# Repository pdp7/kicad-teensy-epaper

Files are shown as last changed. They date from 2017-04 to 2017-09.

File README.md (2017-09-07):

# E-Paper Badge with Teensy LC designed in KiCad
E-Paper badge designed in [KiCad](http://kicad-pcb.org/) to connect [Pervasive Displays 2.15" E-Paper](http://www.digikey.com/product-detail/en/pervasive-displays/E2215CS062/E2215CS062-ND/5975949) to [Teensy LC](http://store.oshpark.com/products/teensy-lc). _([Teensy 3.2](https://oshpark.com/teensy) is also compatible)._  Based [Teensy E-Paper Shield](https://blog.oshpark.com/2016/08/27/teensy-e-paper-shield/) by [Jarek Lupinski](https://hackaday.io/Jarek) in EAGLE.

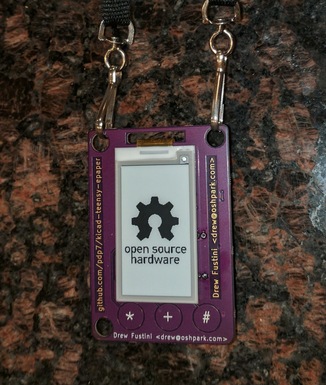
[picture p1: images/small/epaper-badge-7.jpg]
Photo of E-Paper Display (https://oshpark.com/shared_projects/VzRNemk1)

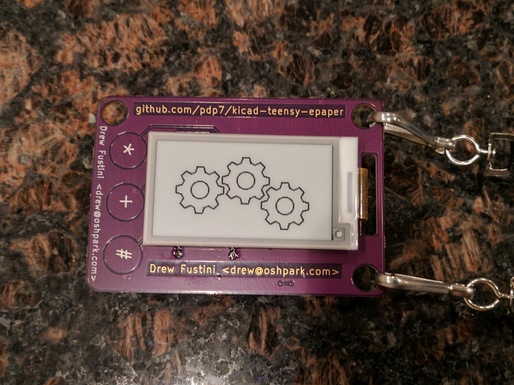
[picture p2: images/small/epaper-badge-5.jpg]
Additional Photo of E-Paper Display (https://oshpark.com/shared_projects/VzRNemk1)


## OSH Park shared project
* [KiCad Teensy E-Paper Badge](https://oshpark.com/shared_projects/VzRNemk1)

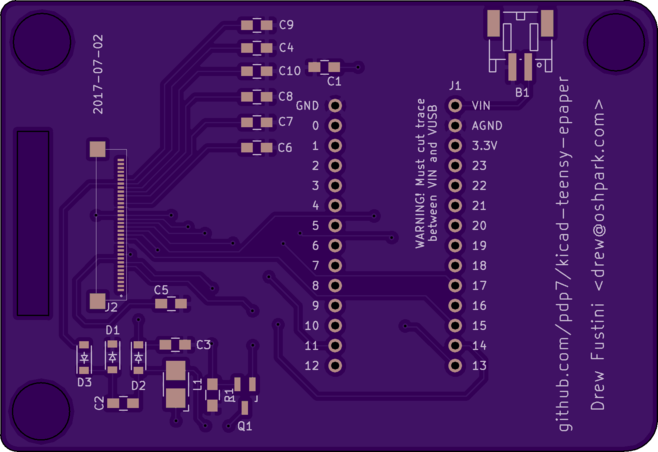
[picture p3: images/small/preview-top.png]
Preview of PCB top side (https://oshpark.com/shared_projects/VzRNemk1)


## KiCad PCB design files
* repo: [kicad-teensy-epaper](https://github.com/pdp7/kicad-teensy-epaper/)
* commit: [add JST connector for lipo battery [abcafec]](https://github.com/pdp7/kicad-teensy-epaper/commit/abcafeccad423acb4cc5d59347c79b58a7b5082b)
* requires KiCad library [wickerlib](https://github.com/wickerbox/wickerlib) by [Jenner Hanni](http://jennerhanni.net/) of [Wickerbox Electronics](http://wickerbox.net/) for the 34-position FPC connector that the e-paper display plugs into:
  * [CONN-HEADER-FH34SRJ-34S-0.5SH.kicad_mod](https://github.com/wickerbox/wickerlib/blob/master/libraries/Wickerlib.pretty/CONN-HEADER-FH34SRJ-34S-0.5SH.kicad_mod)

## Bill of Materials (BoM)
* [OSH Stencils](https://www.oshstencils.com/#projects/83952319ea2abc27d46ef9cab843063dbfd85e58): stainless steel stencil
* [Teensy LC](http://store.oshpark.com/products/teensy-lc) sold by OSH Park. Designed and manufactured by [PJRC](https://www.pjrc.com/teensy/teensyLC.html).
  * _[Teensy 3.2](https://oshpark.com/teensy) is also compatible but more expensive_
* [Pervasive Displays 2.15" e-paper with ITC](http://www.pervasivedisplays.com/products/215)
  * Mfg part number: E2215CS062
  * Digi-Key: [E2215CS062-ND](http://www.digikey.com/product-detail/en/pervasive-displays/E2215CS062/E2215CS062-ND/5975949)
  * Datasheet: [2.15" TFT EPD Panel (E2215CS062)](http://www.pervasivedisplays.com/LiteratureRetrieve.aspx?ID=232067)
  * App note: [2.15" Aurora_Mb Application Note](http://www.pervasivedisplays.com/LiteratureRetrieve.aspx?ID=232068)
* [Hirose FH34SRJ-34S-0.5SH FPC connector](https://www.digikey.com/short/3hv1q0)
  * Mfg part number: FH34SRJ-34S-0.5SH(99)
  * Digi-Key: [H124726CT-ND](https://www.digikey.com/short/3hv1q0)
  * Datasheet: [FH34(S) Series Datasheet](https://www.hirose.com/product/en/download_file/key_name/FH34SRJ/category/Catalog/doc_file_id/31646/?item_id=27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)
* [JST connector for LiPo battery](https://www.digikey.com/short/312bmm)
  * Mfg part number: S2B-PH-SM4-TB(LF)(SN)
  * Digikey: [455-1749-1-ND](https://www.digikey.com/short/312bmm) _(CONN HEADER PH SIDE 2POS 2MM SMD)_
  * Datasheet: [JST PH connector](http://www.jst-mfg.com/product/pdf/eng/ePH.pdf)  
* Teensy headers
  * Digikey: [S7012-ND](https://www.digikey.com/short/3db830) _(CONN HEADER FEMALE 14POS.1" TIN)_
  * optional as Teensy can be soldered directly to PCB
* Capacitor 1uF 0805 _(quantity 9)_
  * Digi-Key: [1276-1066-1-ND](https://www.digikey.com/short/3db8tm) _(CAP CER 1UF 25V X7R 0805)_
  * Reference: C1 C3 C4 C5 C6 C7 C8 C9 C10
  * _Note: it is cheaper to purhcase qty 10_
* Capacitor 2.2uF 0805
  * Digi-Key: [1276-2953-1-ND](https://www.digikey.com/short/3db8tp) _(CAP CER 2.2UF 25V X7R 0805)_
  * Reference: C2
* Inductor 47uH
  * Digi-Key: [732-7252-1-ND](https://www.digikey.com/short/3db8tq) _(FIXED IND 47UH 800MA 521 MOHM)_
  * Reference: L1
* Mosfet N-Ch SOT23
  * Digi-Key: [785-1012-1-ND](https://www.digikey.com/short/3db8t8) _(MOSFET N-CH 30V 3.8A SOT23)_
  * Reference: Q1
* Resistor 2.2 Ohm 0805
  * Digi-Key: [311-2.20CRCT-ND](https://www.digikey.com/short/3db8tz) _(RES SMD 2.2 OHM 1% 1/8W 0805)_
  * Reference: R1
* Schotty diodes SOD123 _(quantity 3)_
  * Digi-Key: [MBR0530CT-ND](https://www.digikey.com/short/3db883) _(DIODE SCHOTTKY 30V 500MA SOD123)_
  * Reference: D1 D2 D3

### [Digi-Key shopping cart](http://www.digikey.com/short/312b57)
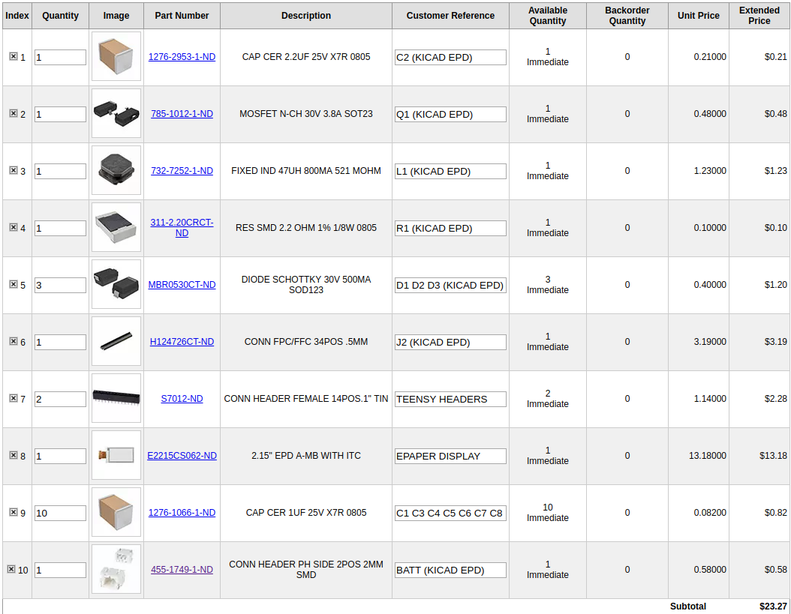
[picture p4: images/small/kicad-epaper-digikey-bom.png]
Digi-Key shopping cart


### Battery Power
* **WARNING: The trace between VIN and VUSB must be cut!**
  * [Demostration of cutting the trace](https://learn.adafruit.com/assets/28069) on Adafruit Learning System.
* **[Lithium Ion Polymer Battery - 3.7v 500mAh](https://www.adafruit.com/product/1578)** from Adafruit
  * capacity chosen for a good trade off between weight and power
  * TODO: measure how long board will run with different capacities.

## Source Code
* uses [EPD215](https://github.com/jarek319/EPD215) Arduino Library by Jarek Lupinski for his E-paper Teensy Shield
* requires pinout modification:
  * example: [bringahackmfba17-dorkbotpdx.ino](https://github.com/pdp7/kicad-teensy-epaper/blob/master/firmware/bringahackmfba17-dorkbotpdx/bringahackmfba17-dorkbotpdx.ino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)
  * `EPD215 epaper( 17, 16, 14, 15, 13, 11 );`
 * rotation hack in [`EPD215.cpp`](https://github.com/pdp7/EPD215/commit/f4e22660877759e53a3a83ed35c6e7a54616d285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)
   * text and graphics wil be upside down without this
   * [quick hack to set rotation](https://github.com/pdp7/EPD215/commit/f4e22660877759e53a3a83ed35c6e7a54616d285) based on [Adafruit documentation](https://learn.adafruit.com/adafruit-gfx-graphics-library/rotating-the-display): 
   * Landscape mode:
     * `_rotation = 1`
   * Portrait mode:
     * `_rotation = 2`
   * I don't use this for the examples program that just display bitmaps as I just flip the image before generating the byte array from the bitmap file

**TODO:** library should be modified to accept rotation parameter
  
## Photos
* [Google Photos gallery](https://goo.gl/photos/csZV9jxah2BSP6vG9)
* [images directory in github repo](https://github.com/pdp7/kicad-teensy-epaper/tree/master/images)

## Video
* [YouTube: *E-Paper Badge with Teensy LC designed in KiCad*](https://www.youtube.com/watch?v=AxnLgPFTEOA)

## Related: Jarek's ePaper Teensy shield
  * OSH Park shared project: [Teensy e-Paper shield](https://oshpark.com/shared_projects/3KynIVn6)
  * My repo of Jarek's design files: [TeensyEpaperShield](https://github.com/pdp7/TeensyEpaperShield)

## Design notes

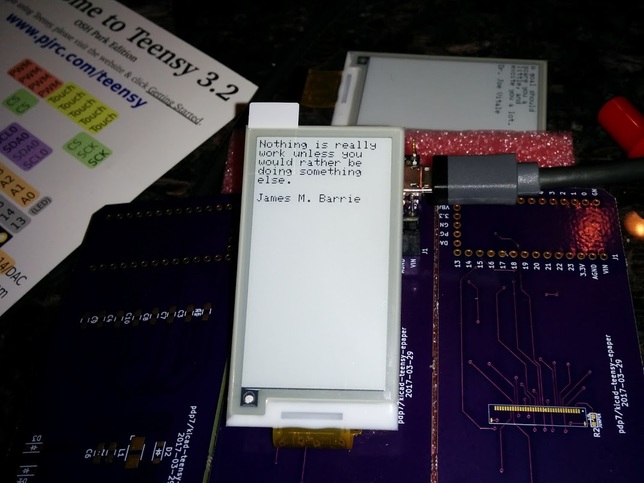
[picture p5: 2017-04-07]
images/small/epaper-breakout-board-quotes.jpg

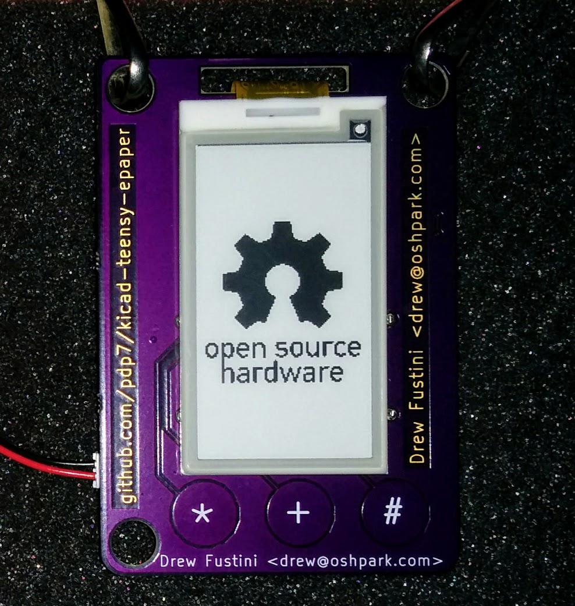
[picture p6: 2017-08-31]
images/front-2.jpg

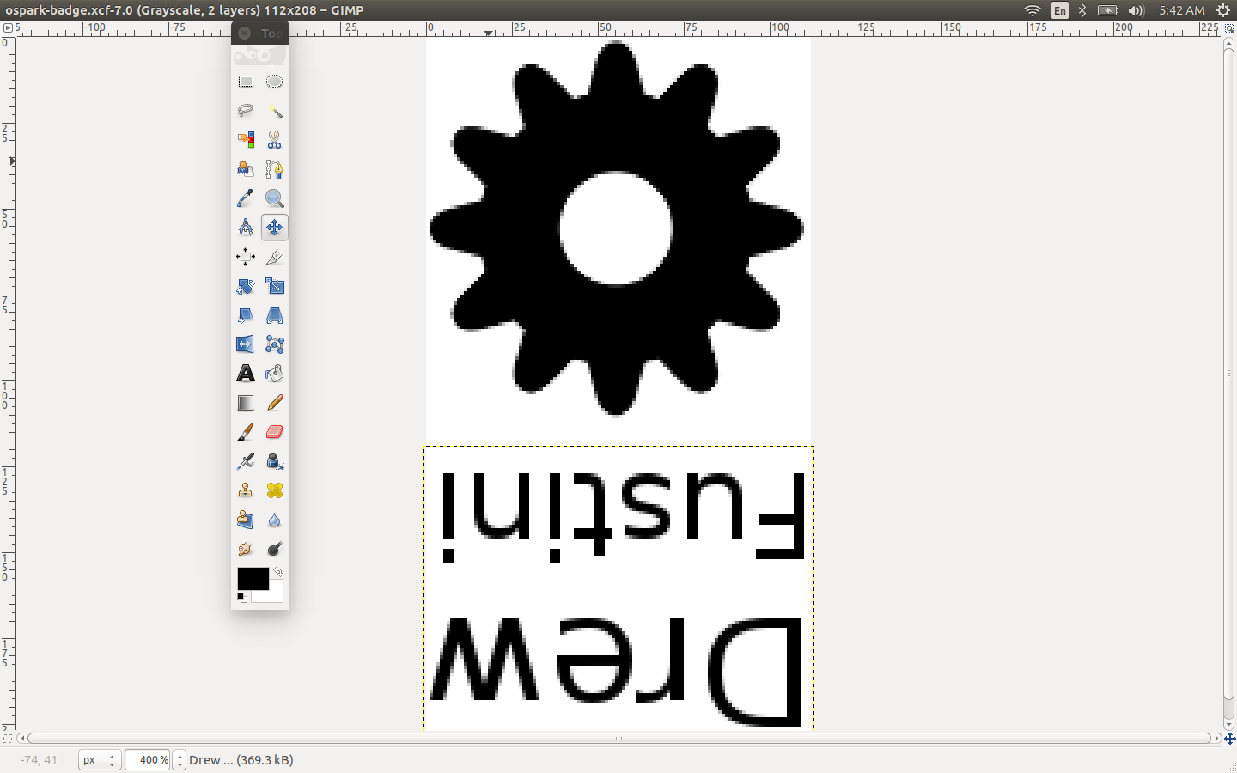
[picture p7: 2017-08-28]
doc/gimp-name.png

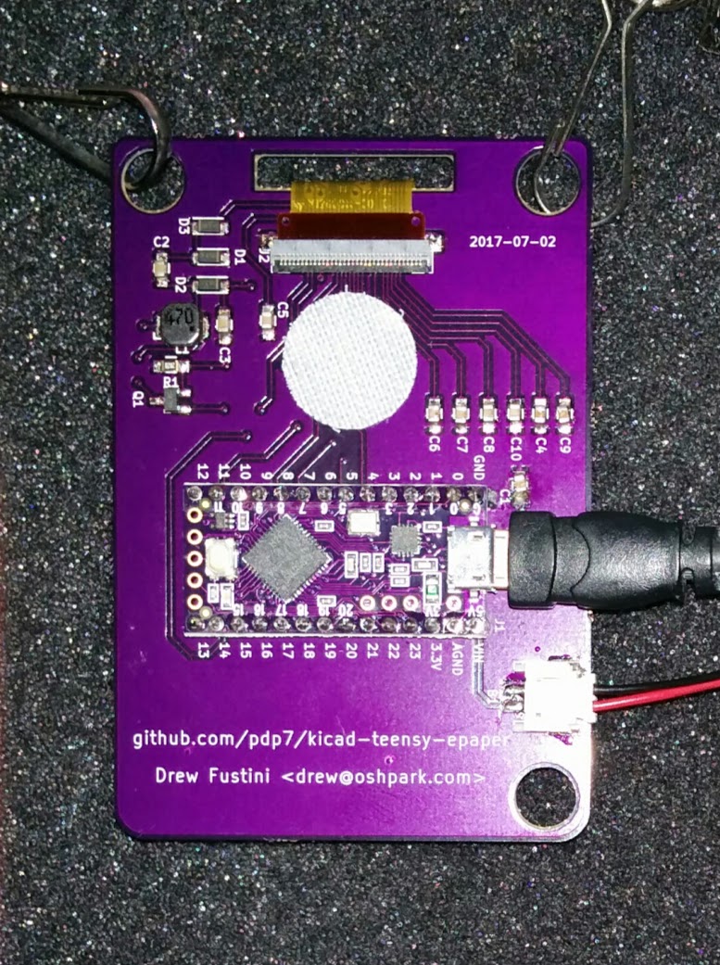
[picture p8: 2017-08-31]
images/back-2.jpg

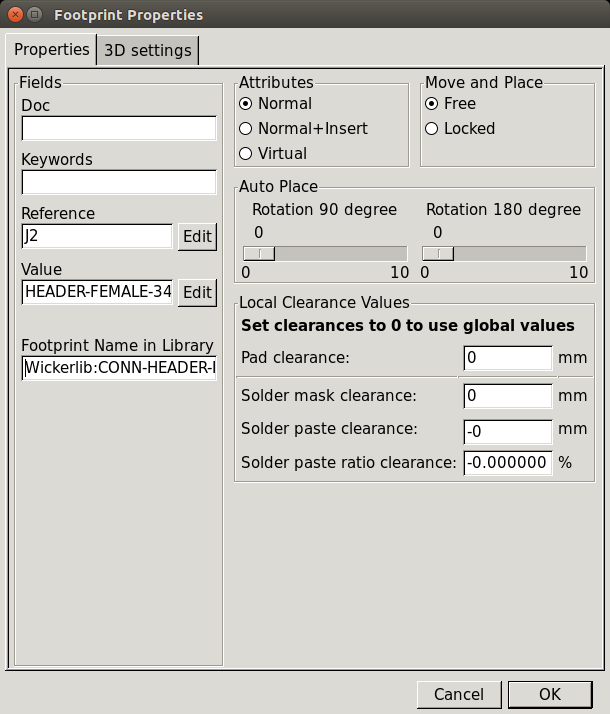
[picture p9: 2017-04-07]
images/fpc-34pos-footprint-props.png

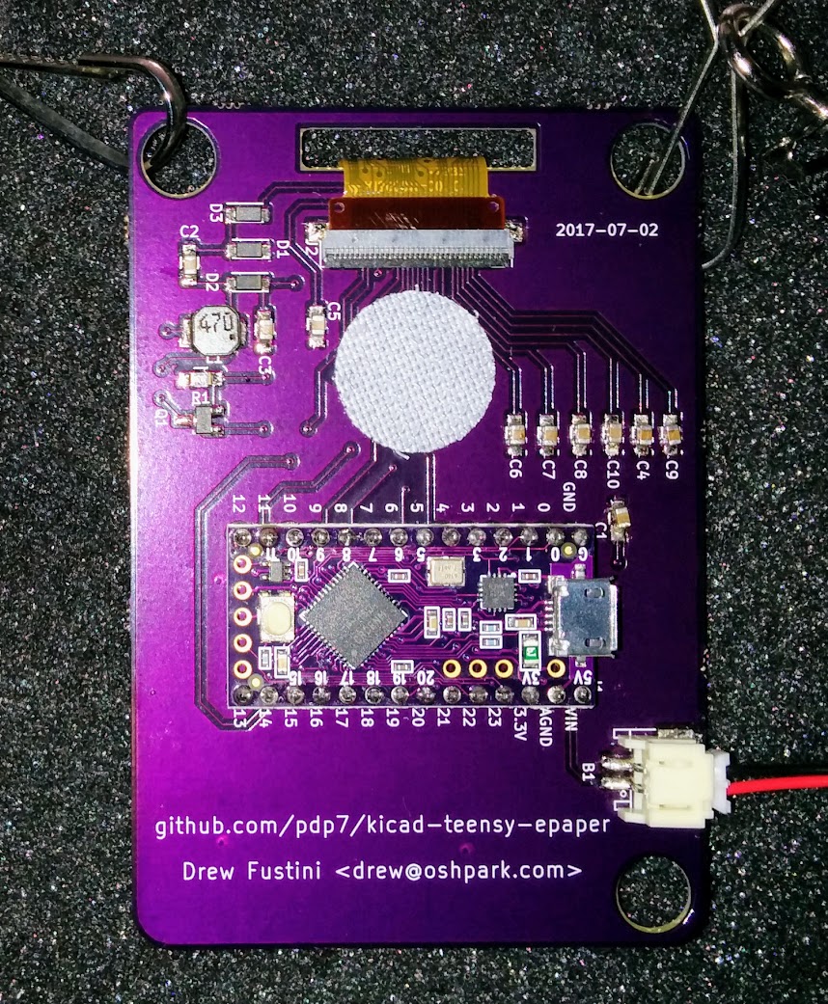
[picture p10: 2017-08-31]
images/back-1.jpg

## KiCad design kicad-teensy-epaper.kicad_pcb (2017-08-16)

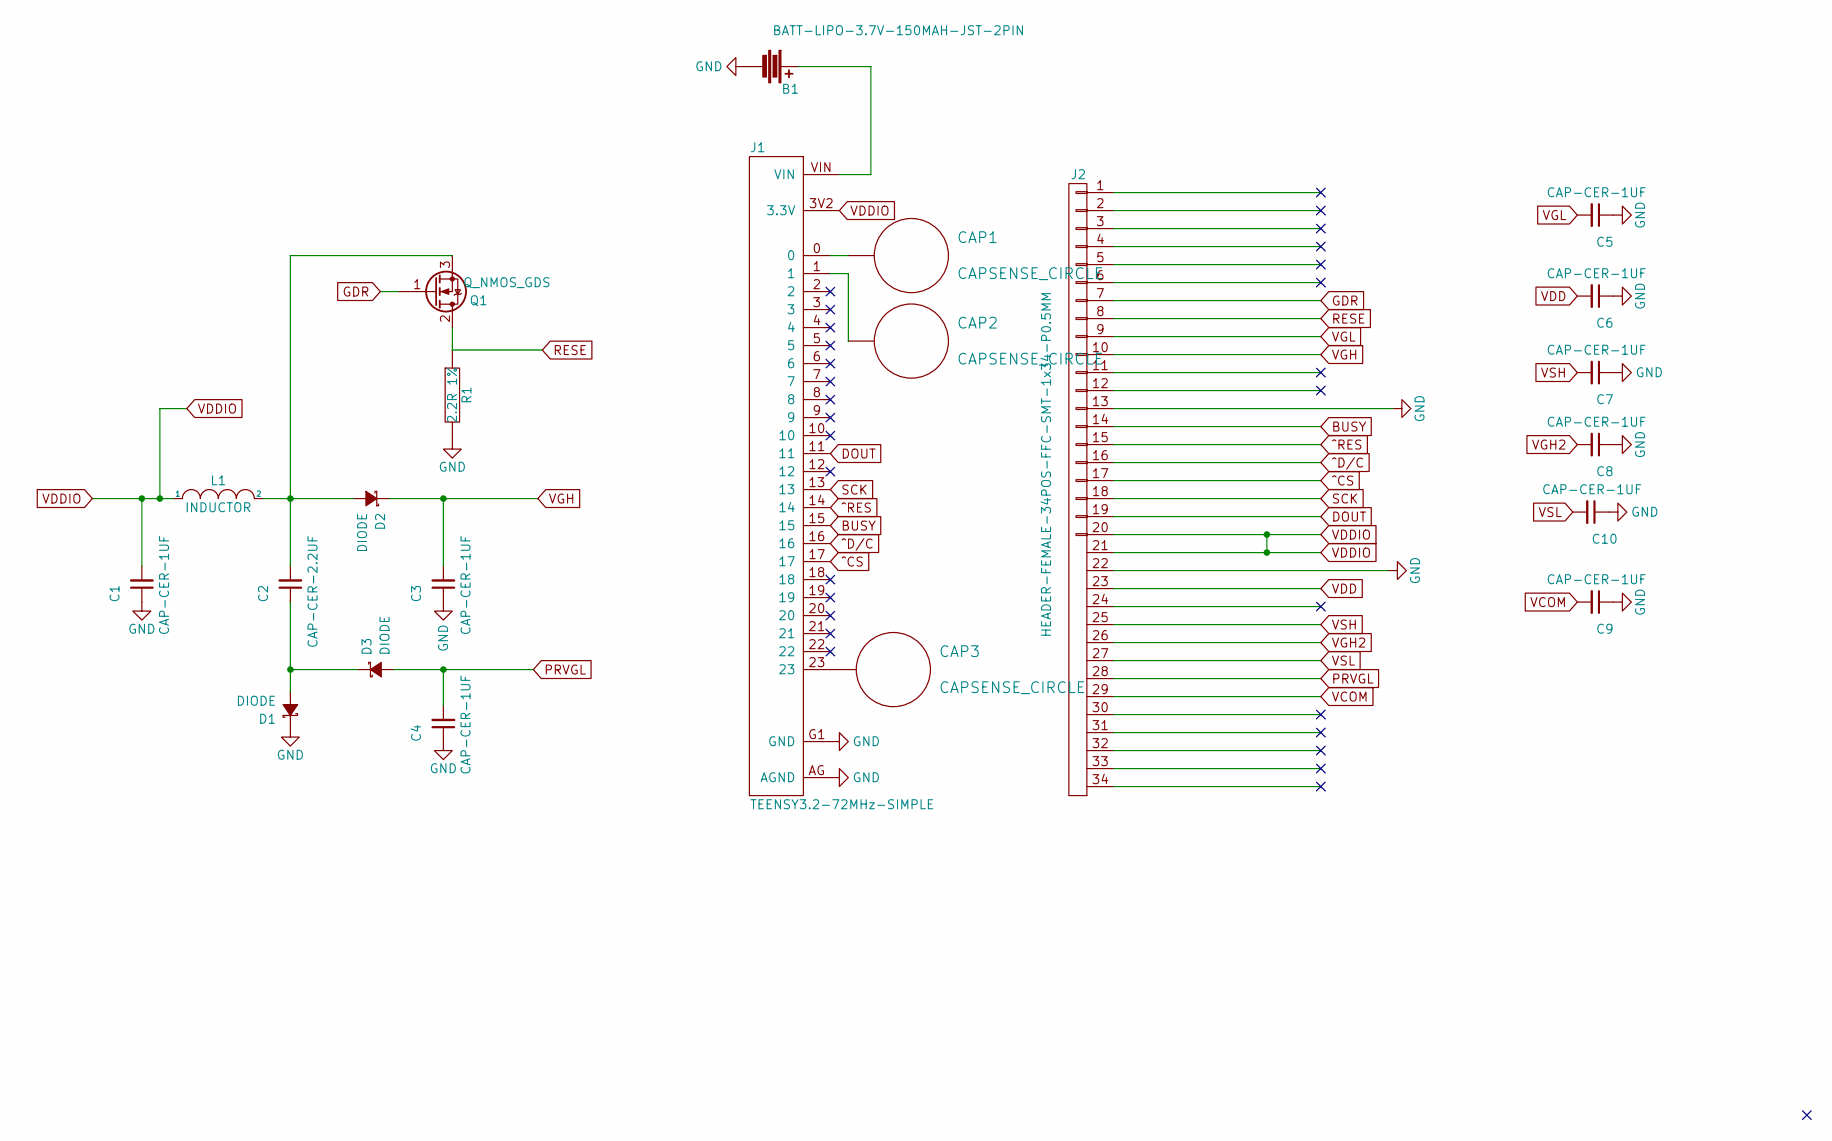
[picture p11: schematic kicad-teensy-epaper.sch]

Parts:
B1: BATT-LIPO-3.7V-150MAH-JST-2PIN; JST_PH_B2B-PH-SM4-TB_02x2.00mm_Straight
C1, C3, C4, C5, C6, C7, C8, C9, C10: CAP-CER-1UF; C_0805_HandSoldering
C2: CAP-CER-2.2UF; C_0805_HandSoldering
CAP1, CAP2, CAP3: CAPSENSE_CIRCLE; CAPSENSE-CIRCLE-D10MM
D1, D2, D3: DIODE; SOD-123
J1: TEENSY3.2-72MHz-SIMPLE; TEENSY-3.2-SILK-SIMPLE
J2: HEADER-FEMALE-34POS-FFC-SMT-1x34-P0.5MM; CONN-HEADER-FH34SRJ-34S-0.5SH
L1: INDUCTOR; Inductor_1212
Q1: Q_NMOS_GDS; SOT-23_Handsoldering
R1: 2.2R 1%; R_0805_HandSoldering

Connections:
BUSY: J1.15, J2.14
DOUT: J1.11, J2.19
GDR: J2.7, Q1.1 (G)
GND: B1.2, C1.1, C3.1, C4.1, C5.1, C6.1, C7.1, C8.1, C9.1, C10.1, D1.1 (K), J1.AG (AGND), J1.G1 (GND), J2.13, J2.22, R1.2
unnamed: B1.1, J1.VIN
unnamed: C2.1, D1.2 (A), D3.1 (K)
unnamed: C2.2, D2.2 (A), L1.2, Q1.3 (S)
unnamed: CAP1.1, J1.0
unnamed: CAP2.1, J1.1
unnamed 9: CAP3.1, J1.23; also elsewhere on the board
PRVGL: C4.2, D3.2 (A), J2.28
RESE: J2.8, Q1.2 (D), R1.1
SCK: J1.13, J2.18
VCOM: C9.2, J2.29
VDD: C6.2, J2.23
VDDIO: C1.2, J1.3V2 (3.3V), J2.20, J2.21, L1.1
VGH: C3.2, D2.1 (K), J2.10
VGH2: C8.2, J2.26
VGL: C5.2, J2.9
VSH: C7.2, J2.25
VSL: C10.2, J2.27
^CS: J1.17, J2.17
^D/C: J1.16, J2.16
^RES: J1.14, J2.15

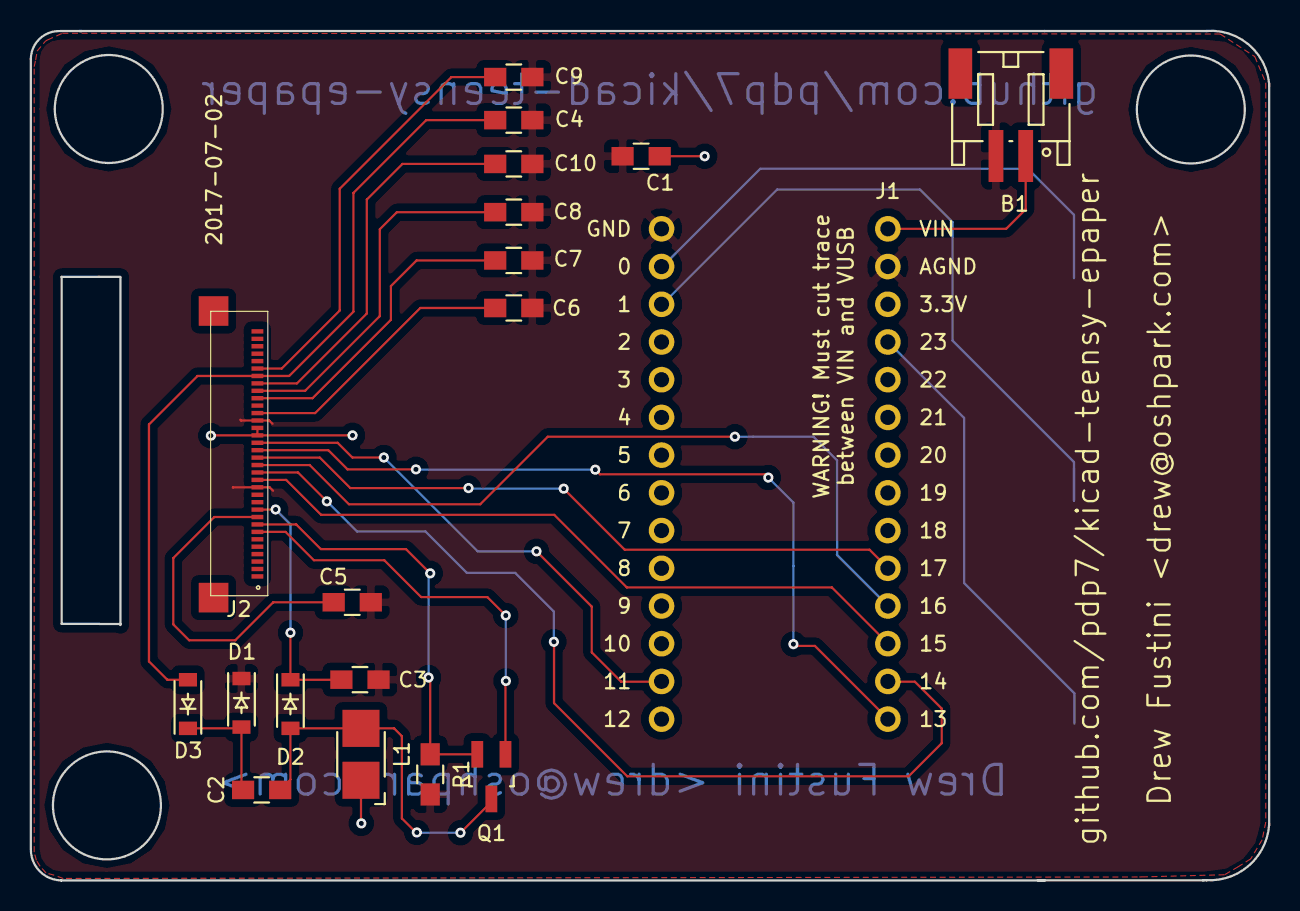
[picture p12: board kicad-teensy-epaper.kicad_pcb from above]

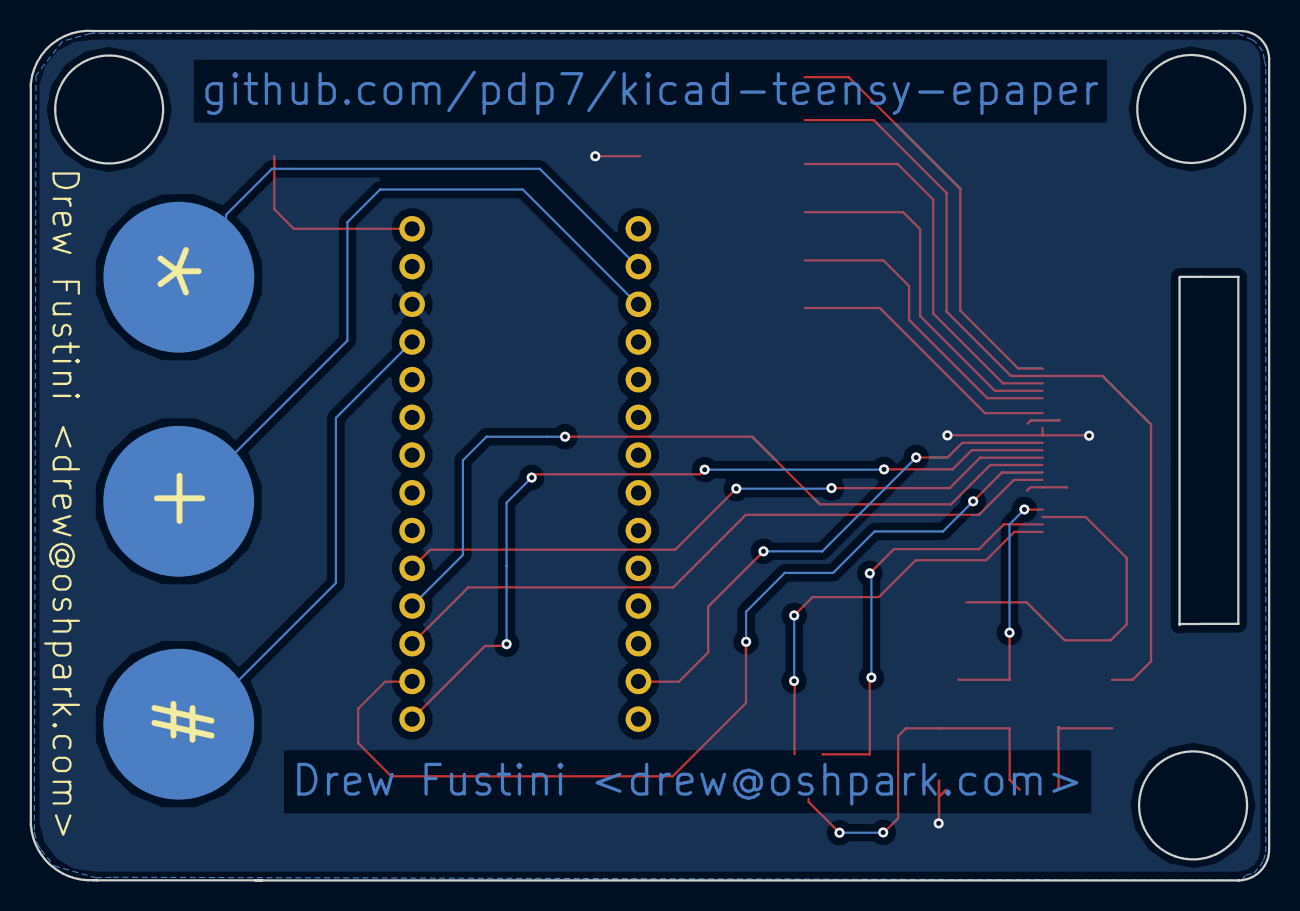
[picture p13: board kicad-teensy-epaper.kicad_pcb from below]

Board: 2 copper layers, 83.4 x 57.2 mm, 22 parts (3 on the bottom side), 24 nets.

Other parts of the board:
A: CAPSENSE_CIRCLE; CAPSENSE-CIRCLE-D10MM

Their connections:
unnamed 9: A.1; also elsewhere on the board

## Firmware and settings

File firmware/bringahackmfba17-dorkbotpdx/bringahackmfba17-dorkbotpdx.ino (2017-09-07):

#include <Adafruit_GFX.h> // include the base Adafruit Graphics library
#include <EPD215.h>       // include the epaper display driver library

// initialize epaper with pin numbers for cs, dc, rs, bs, d0, d1 for software SPI
//EPD215 epaper( 17, 16, 14, 15, 13, 11 );
EPD215 epaper( 17, 16, 14, 15, 13, 11 );


// use the tool at http://javl.github.io/image2cpp/ to generate the block of data below
// settings are: Canvas size/s: 112 x 208 , Draw Mode: Horizontal
// use other settings to make white = 0 and black = 1
const uint8_t bitmap[ 2912 ] = { // overwrite the block of data between the lines with your image data
0x00, 0x00, 0x00, 0x00, 0x00, 0x00, 0x00, 0x00, 0x00, 0x00, 0x00, 0x00, 0x00, 0x00, 0x00, 0x00,
0x00, 0x00, 0x00, 0x00, 0x00, 0x00, 0x00, 0x00, 0x00, 0x00, 0x00, 0x00, 0x00, 0x00, 0x00, 0x00,
0x00, 0x00, 0x07, 0xC0, 0x00, 0x00, 0x00, 0x00, 0x00, 0x00, 0x00, 0x00, 0x00, 0x00, 0x00, 0x00,
0x0F, 0xE0, 0x00, 0x00, 0x00, 0x00, 0x00, 0x00, 0x00, 0x00, 0x00, 0x00, 0x00, 0x00, 0x1F, 0xE0,
0x00, 0x00, 0x00, 0x00, 0x00, 0x00, 0x00, 0x00, 0x00, 0x00, 0x00, 0x00, 0x1F, 0xF0, 0x00, 0x00,
0x00, 0x00, 0x00, 0x00, 0x00, 0x00, 0x00, 0x00, 0x00, 0x00, 0x3F, 0xF0, 0x00, 0x00, 0x00, 0x00,
0x00, 0x00, 0x00, 0x00, 0x00, 0x00, 0x00, 0x00, 0x3F, 0xF8, 0x00, 0x00, 0x00, 0x00, 0x00, 0x00,
0x00, 0x00, 0x00, 0x00, 0x00, 0x00, 0x3F, 0xF8, 0x00, 0x00, 0x00, 0x00, 0x00, 0x00, 0x00, 0x00,
0x00, 0x0F, 0x80, 0x00, 0x7F, 0xF8, 0x00, 0x07, 0xE0, 0x00, 0x00, 0x00, 0x00, 0x00, 0x00, 0x1F,
0xE0, 0x00, 0x7F, 0xF8, 0x00, 0x0F, 0xF0, 0x00, 0x00, 0x00, 0x00, 0x00, 0x00, 0x3F, 0xF0, 0x00,
0x7F, 0xFC, 0x00, 0x1F, 0xF0, 0x00, 0x00, 0x00, 0x00, 0x00, 0x00, 0x3F, 0xF8, 0x00, 0x7F, 0xFC,
0x00, 0x3F, 0xF0, 0x00, 0x00, 0x00, 0x00, 0x00, 0x00, 0x3F, 0xFC, 0x00, 0xFF, 0xFC, 0x00, 0x7F,
0xF0, 0x00, 0x00, 0x00, 0x00, 0x00, 0x00, 0x3F, 0xFE, 0x00, 0xFF, 0xFC, 0x00, 0xFF, 0xF0, 0x00,
0x00, 0x00, 0x00, 0x00, 0x00, 0x3F, 0xFF, 0x00, 0xFF, 0xFE, 0x03, 0xFF, 0xF0, 0x00, 0x00, 0x00,
0x00, 0x00, 0x00, 0x3F, 0xFF, 0x80, 0xFF, 0xFE, 0x07, 0xFF, 0xF0, 0x00, 0x00, 0x00, 0x00, 0x00,
0x00, 0x1F, 0xFF, 0xC3, 0xFF, 0xFF, 0x8F, 0xFF, 0xF0, 0x00, 0x00, 0x00, 0x00, 0x00, 0x00, 0x1F,
0xFF, 0xFF, 0xFF, 0xFF, 0xFF, 0xFF, 0xF0, 0x00, 0x00, 0x00, 0x00, 0x00, 0x00, 0x1F, 0xFF, 0xFF,
0xFF, 0xFF, 0xFF, 0xFF, 0xE0, 0x00, 0x00, 0x00, 0x00, 0x00, 0x00, 0x1F, 0xFF, 0xFF, 0xFF, 0xFF,
0xFF, 0xFF, 0xE0, 0x00, 0x00, 0x00, 0x00, 0x00, 0x00, 0x0F, 0xFF, 0xFF, 0xFF, 0xFF, 0xFF, 0xFF,
0xE0, 0x00, 0x00, 0x00, 0x00, 0x00, 0x00, 0x0F, 0xFF, 0xFF, 0xFF, 0xFF, 0xFF, 0xFF, 0xE0, 0x00,
0x00, 0x00, 0x00, 0x00, 0x00, 0x0F, 0xFF, 0xFF, 0xFF, 0xFF, 0xFF, 0xFF, 0xC0, 0x00, 0x00, 0x00,
0x00, 0x00, 0x00, 0x07, 0xFF, 0xFF, 0xFF, 0xFF, 0xFF, 0xFF, 0xC0, 0x00, 0x00, 0x00, 0x00, 0x00,
0x00, 0x07, 0xFF, 0xFF, 0xFF, 0xFF, 0xFF, 0xFF, 0xC0, 0x00, 0x00, 0x00, 0x00, 0x00, 0x00, 0x07,
0xFF, 0xFF, 0xFF, 0xFF, 0xFF, 0xFF, 0xC0, 0x00, 0x00, 0x00, 0x00, 0x3F, 0xC0, 0x0F, 0xFF, 0xFF,
0xFF, 0xFF, 0xFF, 0xFF, 0xE0, 0x0F, 0xF8, 0x00, 0x00, 0x7F, 0xFC, 0x1F, 0xFF, 0xFF, 0xFF, 0xFF,
0xFF, 0xFF, 0xF0, 0x7F, 0xFC, 0x00, 0x00, 0xFF, 0xFF, 0xFF, 0xFF, 0xFF, 0xFF, 0xFF, 0xFF, 0xFF,
0xFF, 0xFF, 0xFC, 0x00, 0x00, 0xFF, 0xFF, 0xFF, 0xFF, 0xFF, 0xFF, 0xFF, 0xFF, 0xFF, 0xFF, 0xFF,
0xFC, 0x00, 0x00, 0xFF, 0xFF, 0xFF, 0xFF, 0xFF, 0xFF, 0xFF, 0xFF, 0xFF, 0xFF, 0xFF, 0xFC, 0x00,
0x00, 0xFF, 0xFF, 0xFF, 0xFF, 0xFF, 0xFF, 0xFF, 0xFF, 0xFF, 0xFF, 0xFF, 0xFC, 0x00, 0x00, 0x7F,
0xFF, 0xFF, 0xFF, 0xFF, 0xFF, 0xFF, 0xFF, 0xFF, 0xFF, 0xFF, 0xFC, 0x00, 0x00, 0x7F, 0xFF, 0xFF,
0xFF, 0xFF, 0xFF, 0xFF, 0xFF, 0xFF, 0xFF, 0xFF, 0xF8, 0x00, 0x00, 0x3F, 0xFF, 0xFF, 0xFF, 0xFF,
0xFF, 0xFF, 0xFF, 0xFF, 0xFF, 0xFF, 0xF0, 0x00, 0x00, 0x1F, 0xFF, 0xFF, 0xFF, 0xFF, 0xFF, 0xFF,
0xFF, 0xFF, 0xFF, 0xFF, 0xF0, 0x00, 0x00, 0x0F, 0xFF, 0xFF, 0xFF, 0xFF, 0xFF, 0xFF, 0xFF, 0xFF,
0xFF, 0xFF, 0xE0, 0x00, 0x00, 0x07, 0xFF, 0xFF, 0xFF, 0xFF, 0xFF, 0xFF, 0xFF, 0xFF, 0xFF, 0xFF,
0x80, 0x00, 0x00, 0x03, 0xFF, 0xFF, 0xFF, 0xFF, 0xC0, 0x0F, 0xFF, 0xFF, 0xFF, 0xFF, 0x00, 0x00,
0x00, 0x01, 0xFF, 0xFF, 0xFF, 0xFF, 0x00, 0x01, 0xFF, 0xFF, 0xFF, 0xFE, 0x00, 0x00, 0x00, 0x00,
0xFF, 0xFF, 0xFF, 0xFC, 0x00, 0x00, 0x7F, 0xFF, 0xFF, 0xFC, 0x00, 0x00, 0x00, 0x00, 0x7F, 0xFF,
0xFF, 0xF8, 0x00, 0x00, 0x3F, 0xFF, 0xFF, 0xF8, 0x00, 0x00, 0x00, 0x00, 0x3F, 0xFF, 0xFF, 0xF0,
0x00, 0x00, 0x1F, 0xFF, 0xFF, 0xF0, 0x00, 0x00, 0x00, 0x00, 0x7F, 0xFF, 0xFF, 0xE0, 0x00, 0x00,
0x0F, 0xFF, 0xFF, 0xF8, 0x00, 0x00, 0x00, 0x00, 0x7F, 0xFF, 0xFF, 0xC0, 0x00, 0x00, 0x07, 0xFF,
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
};

const uint8_t oshw[ 2912 ] = {
0x00, 0x00, 0x00, 0x00, 0x00, 0x00, 0x00, 0x00, 0x00, 0x00, 0x00, 0x00, 0x00, 0x00, 0x00, 0x00,
0x00, 0x00, 0x00, 0x00, 0x00, 0x00, 0x00, 0x00, 0x00, 0x00, 0x00, 0x00, 0x00, 0x00, 0x00, 0x00,
0x00, 0x00, 0x00, 0x00, 0x00, 0x00, 0x00, 0x00, 0x00, 0x00, 0x00, 0x00, 0x00, 0x00, 0x00, 0x00,
0x00, 0x00, 0x00, 0x00, 0x00, 0x00, 0x00, 0x00, 0x00, 0x00, 0x00, 0x00, 0x00, 0x00, 0x00, 0x00,
0x00, 0x00, 0x00, 0x00, 0x00, 0x00, 0x00, 0x00, 0x00, 0x00, 0x00, 0x00, 0x00, 0x00, 0x00, 0x00,
0x00, 0x00, 0x00, 0x00, 0x00, 0x00, 0x00, 0x00, 0x00, 0x00, 0x00, 0x00, 0x00, 0x00, 0x00, 0x00,
0x00, 0x00, 0x00, 0x00, 0x00, 0x00, 0x00, 0x00, 0x00, 0x00, 0x00, 0x00, 0x00, 0x00, 0x00, 0x00,
0x00, 0x00, 0x00, 0x00, 0x00, 0x00, 0x00, 0x00, 0x00, 0x00, 0x00, 0x00, 0x00, 0x00, 0x00, 0x00,
0x00, 0x00, 0x00, 0x00, 0x00, 0x00, 0x00, 0x00, 0x00, 0x00, 0x00, 0x00, 0x00, 0x00, 0x00, 0x00,
0x00, 0x00, 0x00, 0x00, 0x00, 0x00, 0x00, 0x00, 0x00, 0x00, 0x00, 0x00, 0x00, 0x00, 0x00, 0x00,
0x00, 0x00, 0x00, 0x00, 0x00, 0x00, 0x00, 0x00, 0x00, 0x00, 0x00, 0x00, 0x00, 0x00, 0x00, 0x00,
0x00, 0x00, 0x00, 0x00, 0x00, 0x00, 0x00, 0x00, 0x00, 0x00, 0x00, 0x00, 0x00, 0x00, 0x00, 0x00,
0x00, 0x00, 0x00, 0x00, 0x00, 0x00, 0x00, 0x00, 0x00, 0x00, 0x00, 0x00, 0x00, 0x00, 0x00, 0x00,
0x00, 0x00, 0x00, 0x00, 0x00, 0x00, 0x00, 0x00, 0x00, 0x00, 0x00, 0x00, 0x00, 0x00, 0x00, 0x00,
0x00, 0x00, 0x00, 0x00, 0x00, 0x00, 0x00, 0x00, 0x00, 0x00, 0x00, 0x00, 0x00, 0x00, 0x00, 0x00,
0x00, 0x00, 0x00, 0x00, 0x00, 0x00, 0x00, 0x00, 0x00, 0x00, 0x00, 0x00, 0x00, 0x00, 0x00, 0x00,
0x00, 0x00, 0x00, 0x00, 0x00, 0x00, 0x00, 0x00, 0x00, 0x00, 0x00, 0x00, 0x00, 0x00, 0x00, 0x00,
0x00, 0x00, 0x00, 0x00, 0x00, 0x00, 0x00, 0x00, 0x00, 0x00, 0x00, 0x00, 0x00, 0x00, 0x00, 0x00,
0x00, 0x00, 0x00, 0x00, 0x00, 0x00, 0x00, 0x00, 0x00, 0x00, 0x00, 0x00, 0x00, 0x00, 0x00, 0x00,
0x00, 0x00, 0x00, 0x00, 0x00, 0x00, 0x00, 0x00, 0x00, 0x00, 0x00, 0x00, 0x00, 0x00, 0x00, 0x00,
0x00, 0x00, 0x00, 0x00, 0x00, 0x00, 0x00, 0x00, 0x00, 0x00, 0x00, 0x00, 0x00, 0x00, 0x00, 0x00,
0x00, 0x00, 0x00, 0x00, 0x00, 0x00, 0x00, 0x00, 0x00, 0x00, 0x00, 0x00, 0x00, 0x00, 0x00, 0x00,
0x00, 0x00, 0x00, 0x00, 0x00, 0x00, 0x00, 0x00, 0x00, 0x00, 0x00, 0x00, 0x00, 0x00, 0x00, 0x00,
0x00, 0x00, 0x00, 0x00, 0x00, 0x00, 0x00, 0x00, 0x00, 0x00, 0x00, 0x00, 0x00, 0x00, 0x00, 0x00,
0x00, 0x00, 0x00, 0x00, 0x00, 0x00, 0x00, 0x00, 0x00, 0x00, 0x00, 0x00, 0x00, 0x00, 0x00, 0x00,
0x00, 0x00, 0x00, 0x00, 0x00, 0x00, 0x00, 0x00, 0x00, 0x00, 0x00, 0x00, 0x00, 0x00, 0x00, 0x00,
0x00, 0x00, 0x00, 0x00, 0x00, 0x00, 0x00, 0x00, 0x00, 0x00, 0x00, 0x00, 0x00, 0x00, 0x00, 0x00,
0x00, 0x00, 0x00, 0x00, 0x00, 0x00, 0x00, 0x00, 0x00, 0x00, 0x00, 0x00, 0x00, 0x00, 0x00, 0x00,
0x00, 0x00, 0x00, 0x00, 0x00, 0x00, 0x00, 0x00, 0x00, 0x00, 0x00, 0x00, 0x00, 0x00, 0x00, 0x00,
0x00, 0x00, 0x00, 0x00, 0x00, 0x00, 0x00, 0x00, 0x00, 0x00, 0x00, 0x00, 0x00, 0x00, 0x00, 0x00,
0x00, 0x00, 0x00, 0x00, 0x00, 0x00, 0x00, 0x00, 0x00, 0x00, 0x00, 0x00, 0x00, 0x00, 0x00, 0x00,
0x00, 0x00, 0x00, 0x00, 0x00, 0x00, 0x00, 0x00, 0x00, 0x00, 0x00, 0x00, 0x00, 0x00, 0x00, 0x00,
0x00, 0x00, 0x00, 0x00, 0x00, 0x00, 0x00, 0x00, 0x00, 0x00, 0x00, 0x00, 0x00, 0x00, 0x00, 0x00,
0x00, 0x00, 0x00, 0x00, 0x00, 0x00, 0x00, 0x00, 0x00, 0x00, 0x00, 0x00, 0x00, 0x00, 0x00, 0x00,
0x00, 0x00, 0x00, 0x00, 0x00, 0x00, 0x00, 0x00, 0x00, 0x00, 0x00, 0x00, 0x00, 0x00, 0x00, 0x00,
0x00, 0x00, 0x00, 0x00, 0x00, 0x00, 0x00, 0x00, 0x00, 0x00, 0x00, 0x00, 0x00, 0x00, 0x00, 0x00,
0x00, 0x00, 0x00, 0x00, 0x00, 0x00, 0x00, 0x00, 0x00, 0x00, 0x00, 0x00, 0x00, 0x00, 0x00, 0x00,
0x00, 0x00, 0x00, 0x00, 0x00, 0x00, 0x00, 0x00, 0x00, 0x00, 0x00, 0x00, 0x00, 0x00, 0x00, 0x00,
0x00, 0x00, 0x00, 0x00, 0x00, 0x00, 0x00, 0x00, 0x00, 0x00, 0x00, 0x00, 0x00, 0x00, 0x00, 0x00,
0x00, 0x00, 0x00, 0x00, 0x00, 0x00, 0x00, 0x00, 0x00, 0x00, 0x00, 0x00, 0x00, 0x00, 0x00, 0x00,
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
};

const uint8_t pdx [ 2912 ] = {
  0x00, 0x00, 0x00, 0x00, 0x48, 0x00, 0x00, 0x00, 0x09, 0x00, 0x00, 0x00, 0x00, 0x00, 0x00, 0x00,
0x00, 0x00, 0x48, 0x00, 0x00, 0x00, 0x09, 0x00, 0x00, 0x00, 0x00, 0x00, 0x00, 0x00, 0x00, 0x00,
0x48, 0x00, 0x00, 0x00, 0x09, 0x00, 0x00, 0x00, 0x00, 0x00, 0x00, 0x00, 0x00, 0x00, 0x48, 0x00,
0x00, 0x00, 0x09, 0x00, 0x00, 0x00, 0x00, 0x00, 0x00, 0x00, 0x00, 0x00, 0x48, 0x00, 0x00, 0x00,
0x09, 0x00, 0x00, 0x00, 0x00, 0x00, 0x00, 0x00, 0x00, 0x00, 0x48, 0x00, 0x00, 0x00, 0x09, 0x00,
0x00, 0x00, 0x00, 0x00, 0x00, 0x00, 0x00, 0x00, 0x48, 0x00, 0x00, 0x00, 0x09, 0x00, 0x00, 0x00,
0x00, 0x00, 0x00, 0x00, 0x00, 0x00, 0x48, 0x00, 0x00, 0x00, 0x09, 0x00, 0x00, 0x00, 0x00, 0x00,
0x00, 0x00, 0x00, 0x00, 0x48, 0x00, 0x00, 0x00, 0x09, 0x00, 0x00, 0x00, 0x00, 0x00, 0x00, 0x00,
0x00, 0x00, 0x48, 0x00, 0x00, 0x00, 0x09, 0x00, 0x00, 0x00, 0x00, 0x00, 0x00, 0x00, 0x00, 0x00,
0x40, 0x00, 0x00, 0x00, 0x09, 0x00, 0x00, 0x00, 0x00, 0x00, 0x00, 0x00, 0x00, 0x00, 0x40, 0x00,
0x00, 0x00, 0x09, 0x00, 0x00, 0x00, 0x00, 0x00, 0x00, 0x00, 0x00, 0x00, 0x40, 0x00, 0x00, 0x00,
0x09, 0x00, 0x00, 0x00, 0x00, 0x00, 0x00, 0x00, 0x00, 0x00, 0x44, 0x00, 0x00, 0x00, 0x09, 0x00,
0x00, 0x00, 0x00, 0x00, 0x00, 0x00, 0x00, 0x00, 0x44, 0x00, 0x00, 0x00, 0x09, 0x00, 0x00, 0x00,
0x00, 0x00, 0x00, 0x00, 0x00, 0x00, 0x44, 0x00, 0x00, 0x00, 0x09, 0x00, 0x00, 0x00, 0x00, 0x00,
0x00, 0x00, 0x00, 0x00, 0x64, 0x00, 0x00, 0x00, 0x09, 0x00, 0x00, 0x00, 0x00, 0x00, 0x00, 0x00,
0x00, 0x00, 0x24, 0x00, 0x00, 0x00, 0x09, 0x00, 0x00, 0x00, 0x00, 0x00, 0x00, 0x00, 0x00, 0x00,
0x24, 0x00, 0x00, 0x00, 0x09, 0x00, 0x00, 0x00, 0x00, 0x00, 0x00, 0x00, 0x00, 0x00, 0x24, 0x00,
0x00, 0x00, 0x09, 0x00, 0x00, 0x00, 0x00, 0x00, 0x00, 0x00, 0x00, 0x00, 0x24, 0x00, 0x00, 0x00,
0x09, 0x00, 0x00, 0x00, 0x00, 0x00, 0x00, 0x00, 0x00, 0x00, 0x24, 0x00, 0x00, 0x00, 0x09, 0x00,
0x00, 0x00, 0x00, 0x00, 0x00, 0x00, 0x00, 0x00, 0x24, 0x00, 0x00, 0x00, 0x09, 0x00, 0x00, 0x00,
0x00, 0x00, 0x00, 0x00, 0x00, 0x00, 0x24, 0x00, 0x00, 0x00, 0x09, 0x00, 0x00, 0x00, 0x00, 0x00,
0x00, 0x00, 0x00, 0x00, 0x24, 0x00, 0x00, 0x00, 0x09, 0x00, 0x00, 0x00, 0x00, 0x00, 0x00, 0x00,
0x00, 0x00, 0x24, 0x00, 0x00, 0x00, 0x09, 0x00, 0x00, 0x00, 0x00, 0x00, 0x00, 0x00, 0x00, 0x00,
0x24, 0x00, 0x00, 0x00, 0x09, 0x00, 0x00, 0x00, 0x00, 0x00, 0x00, 0x00, 0x00, 0x00, 0x24, 0x00,
0x00, 0x00, 0x09, 0x00, 0x00, 0x00, 0x00, 0x00, 0x00, 0x00, 0x00, 0x00, 0x24, 0x00, 0x00, 0x00,
0x09, 0x00, 0x00, 0x00, 0x00, 0x00, 0x00, 0x00, 0x00, 0x00, 0x20, 0x00, 0x00, 0x00, 0x09, 0x00,
0x00, 0x00, 0x00, 0x00, 0x00, 0x00, 0x00, 0x00, 0x20, 0x00, 0x00, 0x00, 0x09, 0x00, 0x00, 0x00,
0x00, 0x00, 0x00, 0x00, 0x00, 0x00, 0x22, 0x00, 0x00, 0x00, 0x09, 0x00, 0x00, 0x00, 0x00, 0x00,
0x00, 0x00, 0x00, 0x00, 0x22, 0x00, 0x00, 0x00, 0x09, 0x00, 0x00, 0x00, 0x00, 0x00, 0x00, 0x00,
0x00, 0x00, 0x22, 0x00, 0x00, 0x00, 0x09, 0x00, 0x00, 0x00, 0x00, 0x00, 0x00, 0x00, 0x00, 0x00,
0x22, 0x00, 0x00, 0x00, 0x09, 0x00, 0x00, 0x00, 0x00, 0x00, 0x00, 0x00, 0x00, 0x00, 0x22, 0x00,
0x00, 0x00, 0x09, 0x00, 0x00, 0x00, 0x00, 0x00, 0x00, 0x00, 0x00, 0x00, 0x22, 0x00, 0x00, 0x00,
0x09, 0x00, 0x00, 0x00, 0x00, 0x00, 0x00, 0x00, 0x00, 0x00, 0x22, 0x00, 0x00, 0x00, 0x09, 0x00,
0x00, 0x00, 0x00, 0x00, 0x00, 0x00, 0x00, 0x00, 0x22, 0x00, 0x00, 0x00, 0x09, 0x00, 0x00, 0x00,
0x00, 0x00, 0x00, 0x00, 0x00, 0x00, 0x22, 0x00, 0x00, 0x00, 0x09, 0x00, 0x00, 0x00, 0x00, 0x00,
0x00, 0x00, 0x00, 0x00, 0x22, 0x00, 0x00, 0x00, 0x09, 0x00, 0x00, 0x00, 0x00, 0x00, 0x00, 0x00,
0x00, 0x00, 0x22, 0x00, 0x00, 0x00, 0x09, 0x00, 0x00, 0x00, 0x00, 0x00, 0x00, 0x00, 0x00, 0x00,
0x22, 0x00, 0x00, 0x00, 0x09, 0x00, 0x00, 0x00, 0x00, 0x00, 0x00, 0x00, 0x00, 0x00, 0x22, 0x00,
0x00, 0x00, 0x09, 0x00, 0x00, 0x00, 0x00, 0x00, 0x00, 0x00, 0x00, 0x00, 0x22, 0x00, 0x00, 0x00,
0x09, 0x00, 0x00, 0x00, 0x00, 0x00, 0x00, 0x00, 0x00, 0x00, 0x22, 0x00, 0x00, 0x00, 0x09, 0x00,
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
};

void setup() {
  epaper.setRotation(1);
  epaper.initScreen();    // initialize the epaper hardware
  epaper.updateScreen();  // update the screen with whatever is in the buffer
  epaper.clearScreen();   // clear the epaper buffer
  epaper.drawBitmap( 0, 0, pdx, 112, 208, WHITE ); // write the bitmaps to the epaper buffer
  epaper.updateScreen();  // update the screen with whatever is in the buffer
}

void loop() {
  
  delay(10000);
  epaper.clearScreen();   // clear the epaper buffer
  epaper.drawBitmap( 0, 0, bitmap, 112, 208, WHITE ); // write the bitmaps to the epaper buffer
  epaper.updateScreen();  // update the screen with whatever is in the buffer

  delay(10000);
  epaper.clearScreen();   // clear the epaper buffer
  epaper.drawBitmap( 0, 0, oshw, 112, 208, WHITE ); // write the bitmaps to the epaper buffer
  epaper.updateScreen();  // update the screen with whatever is in the buffer

  delay(10000);
  epaper.clearScreen();   // clear the epaper buffer
  epaper.drawBitmap( 0, 0, pdx, 112, 208, WHITE ); // write the bitmaps to the epaper buffer
  epaper.updateScreen();  // update the screen with whatever is in the buffer


}

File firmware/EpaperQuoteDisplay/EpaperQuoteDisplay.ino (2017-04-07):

// From EPD215 by Jarek Lupinski:
// Arduino Library for the E-paper Teensy Shield
// https://github.com/jarek319/EPD215/ 
//
// Source for this file:
// https://github.com/jarek319/EPD215/blob/master/examples/EpaperQuoteDisplay/EpaperQuoteDisplay.ino
// 
// Modified by Drew Fustini for kicad-teensy-epaper projectA
// https://github.com/pdp7/kicad-teensy-epaper/

#include <Adafruit_GFX.h> // include the base Adafruit Graphics library
#include <EPD215.h>       // include the epaper display driver library
#include "quotes.h"       // include a list of the quotes to be displayed

#define ROTATE_DELAY 1   // display a quote for this many minutes before rotating

// initialize epaper with pin numbers for cs, dc, rs, bs, d0, d1 for software SPI
//EPD215 epaper( 17, 16, 15, 14, 13, 11 );
// DREW FUSTINI NOTE: MODIFIED FOR KICAD BREAKOUT BOARD PINOUT
EPD215 epaper( 17, 16, 14, 15, 13, 11 );
// initialize epaper with pin numbers for cs, dc, rs, bs for hardware SPI
//EPD215 epaper( 17, 16, 15, 14 );

void setup() {            // setup function runs once on startup
  Serial.begin( 115200 ); // begin a Serial link in case we need troubleshooting
  delay( 2000 );          // wait two seconds
  epaper.initScreen();    // initialize the epaper hardware
  epaper.updateScreen();  // update the screen with whatever is in the buffer
}

void loop() {                                                        // loop function runs forever until power is removed
  int quoteIndex = random( sizeof( quoteArray ) / 4 );               // get a random quote number
  epaper.clearScreen();                                              // clear the screen
  epaper.setCursor( 0, 0 );                                          // reset the cursor position
  String quoteString = String( quoteArray[ quoteIndex ] );           // get the quote from the array and save it as a String
  Serial.println( quoteString );                                     // print the String out over Serial for troubleshooting
  int delimiterIndex = quoteString.lastIndexOf( ';' );               // find where the quote test ends and the quote author begins
  String textString = quoteString.substring( 0, delimiterIndex );    // store the text of the quote in textString
  String authorString = quoteString.substring( delimiterIndex + 1 ); // store the attributed source of the quote in quoteString
  placeString( textString );                                         // write the text of the string to the e-paper screen buffer
  epaper.println();                                                  // skip two
  epaper.println();                                                  // lines
  placeString( authorString );                                       // write the attributed source of the string to the e-paper screen buffer
  epaper.updateScreen();                                             // update the epaper screen with what is in the buffer
  delay( ROTATE_DELAY * 60000 );                                     // wait ROTATE_DELAY minutes before continuing
}

void placeString( String s ) {  // helper function to implement word-wrapping
  int8_t cursorX = 0;
  for ( uint32_t i = 0; i < s.length(); i ) {
    uint8_t wordEndIndex = s.indexOf( ' ', i );
    int8_t maxLength = 18 - cursorX;
    String wordString = s.substring( i, wordEndIndex );
    int8_t wordStringLength = wordString.length();
    if ( wordStringLength >= maxLength ) { 
      epaper.println();
      cursorX = 0;
    }
    epaper.print( wordString + " " );
    cursorX += wordString.length() + 1;
    i += wordString.length() + 1;
  }
}

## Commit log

2017-01-06 Add initial Kicad project files
    [kicad-teensy-epaper.kicad_pcb, kicad-teensy-epaper.sch]
2017-01-07 create small board to test footprint
    [kicad-teensy-epaper.kicad_pcb, kicad-teensy-epaper.sch]
2017-01-14 start the schematic and layout over
    [kicad-teensy-epaper.kicad_pcb, kicad-teensy-epaper.sch]
2017-02-03 finish redrawing the EAGLE schematic in KiCad
    TODO: make sure the correct parts are used for passives and mosfet
    [kicad-teensy-epaper.kicad_pcb, kicad-teensy-epaper.sch]
2017-02-04 first attempt at layout, 1 air wire remains
    [kicad-teensy-epaper.kicad_pcb, kicad-teensy-epaper.sch]
2017-03-29 order new version
    [kicad-teensy-epaper.kicad_pcb, kicad-teensy-epaper.sch]
2017-03-29 add gerbers
    [kicad-teensy-epaper-B.Cu.gbl, kicad-teensy-epaper-B.Fab.gbr, kicad-teensy-epaper-B.Mask.gbs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]
2017-04-07 add photos of digi-key BoM
2017-04-07 add small image of BoM
2017-04-07 add kicad screenshots
2017-04-08 make ground pads bigger on FPC 34-pos connector
    [kicad-teensy-epaper.kicad_pcb]
2017-04-08 Revert "make ground pads bigger on FPC 34-pos connector"
    This reverts commit 6fa3f84300bf43afcb1b2505809670445bb03ed8.
    This commit was intended for the 'badge' branch
    [kicad-teensy-epaper.kicad_pcb]
2017-04-14 added slot and rerouted traces
    [kicad-teensy-epaper.kicad_pcb, kicad-teensy-epaper.sch]
2017-04-26 redesigned for smaller size and cap touch
    [kicad-teensy-epaper.kicad_pcb, kicad-teensy-epaper.sch]
2017-04-26 label cap touch buttons
    [kicad-teensy-epaper.kicad_pcb]
2017-04-26 update schematic
    [kicad-teensy-epaper.sch]
2017-04-26 move C5 to avoid connector
    [kicad-teensy-epaper.kicad_pcb]
2017-04-26 update layout
    [kicad-teensy-epaper.kicad_pcb]
2017-05-04 Reworked layout for aesthetics
    OSH Park order m5ay7bby on May 4th, 2017.
    [kicad-teensy-epaper.kicad_pcb, kicad-teensy-epaper.sch]
2017-07-03 Set pad soldermask clearance to 0
    The display fine pitch connector footprint
    does not have solder mask between the pads.
    Chris Boros advised I could have solder mask
    between the pads by setting the clearance to 0.
    [kicad-teensy-epaper.kicad_pcb]
2017-07-03 add JST connector for lipo battery
    [kicad-teensy-epaper.kicad_pcb, kicad-teensy-epaper.sch]
2017-08-23 update board preview and digi-key bom images
2017-08-23 update digi-key bom graphic
2017-08-31 update gerbers for most recent layout
    [kicad-teensy-epaper-B.Cu.gbl, kicad-teensy-epaper-B.Fab.gbr, kicad-teensy-epaper-B.Mask.gbs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]
